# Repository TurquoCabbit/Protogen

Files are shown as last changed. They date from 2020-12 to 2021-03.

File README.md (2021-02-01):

# Protogen By Turquo Cabbit and Wolfgasm

* ## Environment setting guide at /firmware/00. environment_setting

* ## Run /firmware/Face2header/APP/New_Gens.exe to add new PROTOGEN or edit exist one
    * ### Enter {Protogen name}, color code, and REMOTE theme number
    * ### Enter face color for REMOTE : R, G, and B within 0 to 255
    * ### Enter REMOTE theme number, theme can be set at /firmware/image/color_theme, follow the folder arrange and naming rule of /00. cyber_neo

* ## Then Run /firmware/Face2header/APP/Face2header.exe to generate header files which content UUID for BLE and Face bitmap
    * ### Face was been set in /firmware/Face2header/Configure/{Protogen name}/LED Matrix.xlsx
    * ### Copy "empty" worksheet to the right of "empty" to add new face
    * ### Remember to fill in face name in the worksheet
    * ### The name of worksheets don't matter however the order of them will be the order of faces in REMOTE.
    * ### !!!DO NOT ADD OR REMOVE ANY WORKSHEET AT LEFT SIDE OF "empty" INCLUDE "empty" ITSELF!!!
    * ### Delete protogen use New_Gens.exe will delete its LED Matrix.xlsx as well, be careful

* ## Program /firmware/Protogen_matrixs/Protogen_matrixs.ino in to ESP32 at PROTOGEN_HEAD
    * ### Have to configur the app space as large as posibale in ESP32 (4MByte) first

* ## Program /firmware/ProtoGun/ProtoGun.ino in to TTGO T-Display in REMOTE
    * ### Have to configur the app space as large as posibale in ESP32 (4MByte) first

* ## TO DO
    * ### PROTOGEN_HEAD
        1. #### Update mainboard PCB made by Wolfgasm
        2. #### Faceture dittering
            * #### even during blinking
        3. #### Vocal sample with amp
            * #### use LM386 for mic amp and to speaker
            * #### ADC
        4. #### Optimize cpp code structure

    * ### REMOTE
        1. #### Translate REMOTE user guide
        2. #### Optimize cpp code structure

#####  Turquo   2021/02/01

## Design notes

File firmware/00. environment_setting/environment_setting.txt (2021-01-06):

00. Arduino Library
	Decompress libraries.zip to C:\Users\[your username]\Documents\Arduino\

01. ESP32_ram
	Copy "Mega_app.csv" to C:\Users\[your username]\AppData\Local\Arduino15\packages\esp32\hardware\esp32\1.0.4\tools\partitions
	Copy "boards.txt" to C:\Users\night\AppData\Local\Arduino15\packages\esp32\hardware\esp32\1.0.4

02. Vscode_ESP32_setting
	a. Install Arduino IDE
	b. Install Arduino plugin from Estensions in Vs code
	c. Fill in Arduino IDE installed path to "Arduino:path" in Vscode setting
	d. From "\02. Vscode_ESP32_setting\Protogen_matrixs" copy ".vscode" and "build_temp" to  "\firmware\Protogen_matrixs"
	e. From "\02. Vscode_ESP32_setting\ProtoGun" copy ".vscode" and "build_temp" to  "\firmware\ProtoGun"
	f. Com port number may be deferent modify it yourself while programing chip

Turquo	2021.01.06

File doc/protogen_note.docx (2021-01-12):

1. I2C Address of LED matrix
  1.1. 000 左邊鼻子 NOSE_L
  1.2. 001 右邊鼻子 NOSE_R
  1.3. 010 左邊眼睛 EYE_L
  1.4. 011 右邊眼睛 EYE_R
  1.5. 100 嘴巴左前 MOUTH_F_L
  1.6. 101 嘴巴右前 MOUTH_F_R
  1.7. 110 嘴巴左後 MOUTH_B_L
  1.8. 111 嘴巴右後 MOUTH_B_R
2. 線色
  2.1. Neopixel
    2.1.1. Vcc => Red
    2.1.2. Din => Blue
    2.1.3. GND => Black
    2.1.4. Dout => White
  2.2. LED Matrix
    2.2.1. Vcc => Red
    2.2.2. GND => Black
    2.2.3. SDA => Blue
    2.2.4. SCL => White
  2.3. PCB 8pin molex
    2.3.1. neopixel => Gray
    2.3.2. fan => Gray
    2.3.3. BZ => Gray
    2.3.4. 3V3 => Red
    2.3.5. SCL => White
    2.3.6. SDA => Blue
    2.3.7. GND => Black
    2.3.8. Vcc => Red
3. https://github.com/2dom/PxMatrix library for RGB matrix
4. E_can
  4.1. ~~風扇至於槍管中段，槍管前段放所有電路，握柄放電池~~
  4.2. 功能
    4.2.1. 螢幕
    4.2.2. 鋰電池電壓偵測/警告 (電壓偏低 風扇停轉，電壓過低關機)
    4.2.3. ~~紅外線搖控(發射/接收)~~
    4.2.4. BLE
    4.2.5. 風扇
      4.2.5.1. https://goods.ruten.com.tw/item/show?21733934233853
      4.2.5.2. BEC電調
    4.2.6. ~~繼電器開關(風扇+總開關)~~
    4.2.7. 按鈕 * 5
    4.2.8. 編碼器 * 1
    4.2.9. ~~DC-DC降壓至5V(LDO add??)~~
    4.2.10. 振動馬達 https://www.sparkfun.com/datasheets/Robotics/310-101_datasheet.pdf
  4.3. 開關機方案
    4.3.1. ~~單鍵開機，常按/選單關機(繼電器自保磁)~~
    4.3.2. ~~https://www.mouser.tw/datasheet/2/378/835-1146852.pdf~~
    4.3.3. 上電開機，偵測電池電壓足夠即開機，六秒後才可控風扇
    4.3.4. ~~長按Return 2秒關機~~
  4.4. 按鈕配置
    4.4.1. enter
    4.4.2. return
    4.4.3. FAN trigger
    4.4.4. X
    4.4.5. Y
    4.4.6. 編碼器 https://tech.alpsalpine.com/prod/c/pdf/encoder/incremental/ec10e/ec10e.pdf
  4.5. TTGO T-display (https://github.com/Xinyuan-LilyGO/TTGO-T-Display)
5. To Do
  5.1. faceture dittering fuction
    5.1.1. even when blinking
  5.2. Bz music
    5.2.1. Driver
    5.2.2. makefile
      5.2.2.1. 簡譜填寫
      5.2.2.2. 轉成陣列
  5.3. Vocal sencing
    5.3.1. LM386
    5.3.2. speaker
  5.4. offline operation
    5.4.1. offline saving
      5.4.1.1. only save remote/gun relate setting
    5.4.2. offline reset
      5.4.2.1. only reset remote/gun relate setting

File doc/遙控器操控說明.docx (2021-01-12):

# 遙控器操控說明

# 1. 主畫面

## 1.1. 顯示

    1.1.1. 頂端顯示電量
    1.1.2. 左下角顯示是否連接上Protogen
    1.1.3. 右下角顯示是否全開亮度
    1.1.4. 中間為當前的表情

## 1.2. 動作

    1.2.1. 滾輪切換表情
    1.2.2. 按一下 ”Enter” 鍵， 發送表情給Protogen
      1.2.2.1. 10 秒未按下Enter發送表情，螢幕將切回顯示當前表情
    1.2.3. 按一下 "X” 鍵，將在當前表情與常用表情間切換
      1.2.3.1. 常用表情設定見 2.3
    1.2.4. 按一下 "Y” 鍵，Beep
      1.2.4.1. Beep模式設定見 2.6.1
    1.2.5. 按一下 "Return" 鍵，LED陣列亮度將在當前亮度與最大亮度間切換
      1.2.5.1. LED陣列亮度設定見 2.4
    1.2.6. 按住"X" 鍵一秒，重新播放或停止動畫
    1.2.7. 按住"Y" 鍵一秒，進入名片頁面
      1.2.7.1. 滾輪翻頁
      1.2.7.2. 按一下任意鍵退出
    1.2.8. 按住 "Return" 鍵一秒進入設定模式

# 2. 設定模式

## 2.1. 按住 "Return" 鍵一秒返回主畫面(無儲存)

## 2.2. Start UP 開機表情

    2.2.1. 滾輪切換表情

## 2.3. Toggle 常用表情

    2.3.1. 滾輪切換表情

## 2.4. Matrix_Bright LED陣列亮度

    2.4.1. 滾輪調整亮度 (0 ~ 15)

## 2.5. Blink 眨眼週期

    2.5.1. 滾輪選擇週期 (2秒 ~ 30秒) 或關閉

## 2.6. BEEP Beep

    2.6.1. MODE 模式
      2.6.1.1. Single 單響
      2.6.1.2. Double 雙響
      2.6.1.3. Rand one 隨機音高單響
      2.6.1.4. Rand two 隨機音高雙響
      2.6.1.5. Rand three 隨機音高三響
      2.6.1.6. 滾輪選擇模式
    2.6.2. PERIOD 週期
      2.6.2.1. 滾輪選擇週期(1 ~ 15 次眨眼) 或關閉
    2.6.3. PITCH 音高
      2.6.3.1. 滾輪往上調高
      2.6.3.2. 滾輪往下調低

## 2.7. BOOP Protosence

    2.7.1. 目前僅有Boop功能
    2.7.2. 滾輪調整開啟或關閉

## 2.8. Neo_Bright Neopixel亮度

    2.8.1. 滾輪調整亮度 (0 ~ 255)

## 2.9. Fan Duty 風量

    2.9.1. 滾輪調整duty cycle (50% ~ 100%)

## 2.10. ADC Cal 電池電壓校準

    2.10.1. 滾輪調整ADC增益
    2.10.2. 將顯示的電池電壓調整至與測量結果相同

## 2.11. Leave 退出

    2.11.1. Don't Save
      2.11.1.1. 不儲存並回到主選單
    2.11.2. Save
      2.11.2.1. 將所有設定發送至Protogen並儲存後回到主選單

## 2.12. Reset 重置

    2.12.1. 按住 "Y" 鍵三秒重置
    2.12.2. 將同時重置連線的Protogen

# 3. 省電

  3.1. 一分鐘未操作UI，關閉LCD背光
  3.2. 按任意鍵(風扇板機除外)或滾動滾輪恢復

# 4. TODO

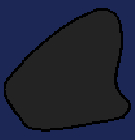
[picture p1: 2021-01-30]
firmware/image/color_theme/00. cyber_neo/Face/Face_empty.jpg

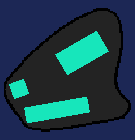
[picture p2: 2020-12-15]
firmware/image/Jpg/00. Spoon/03_Full.png

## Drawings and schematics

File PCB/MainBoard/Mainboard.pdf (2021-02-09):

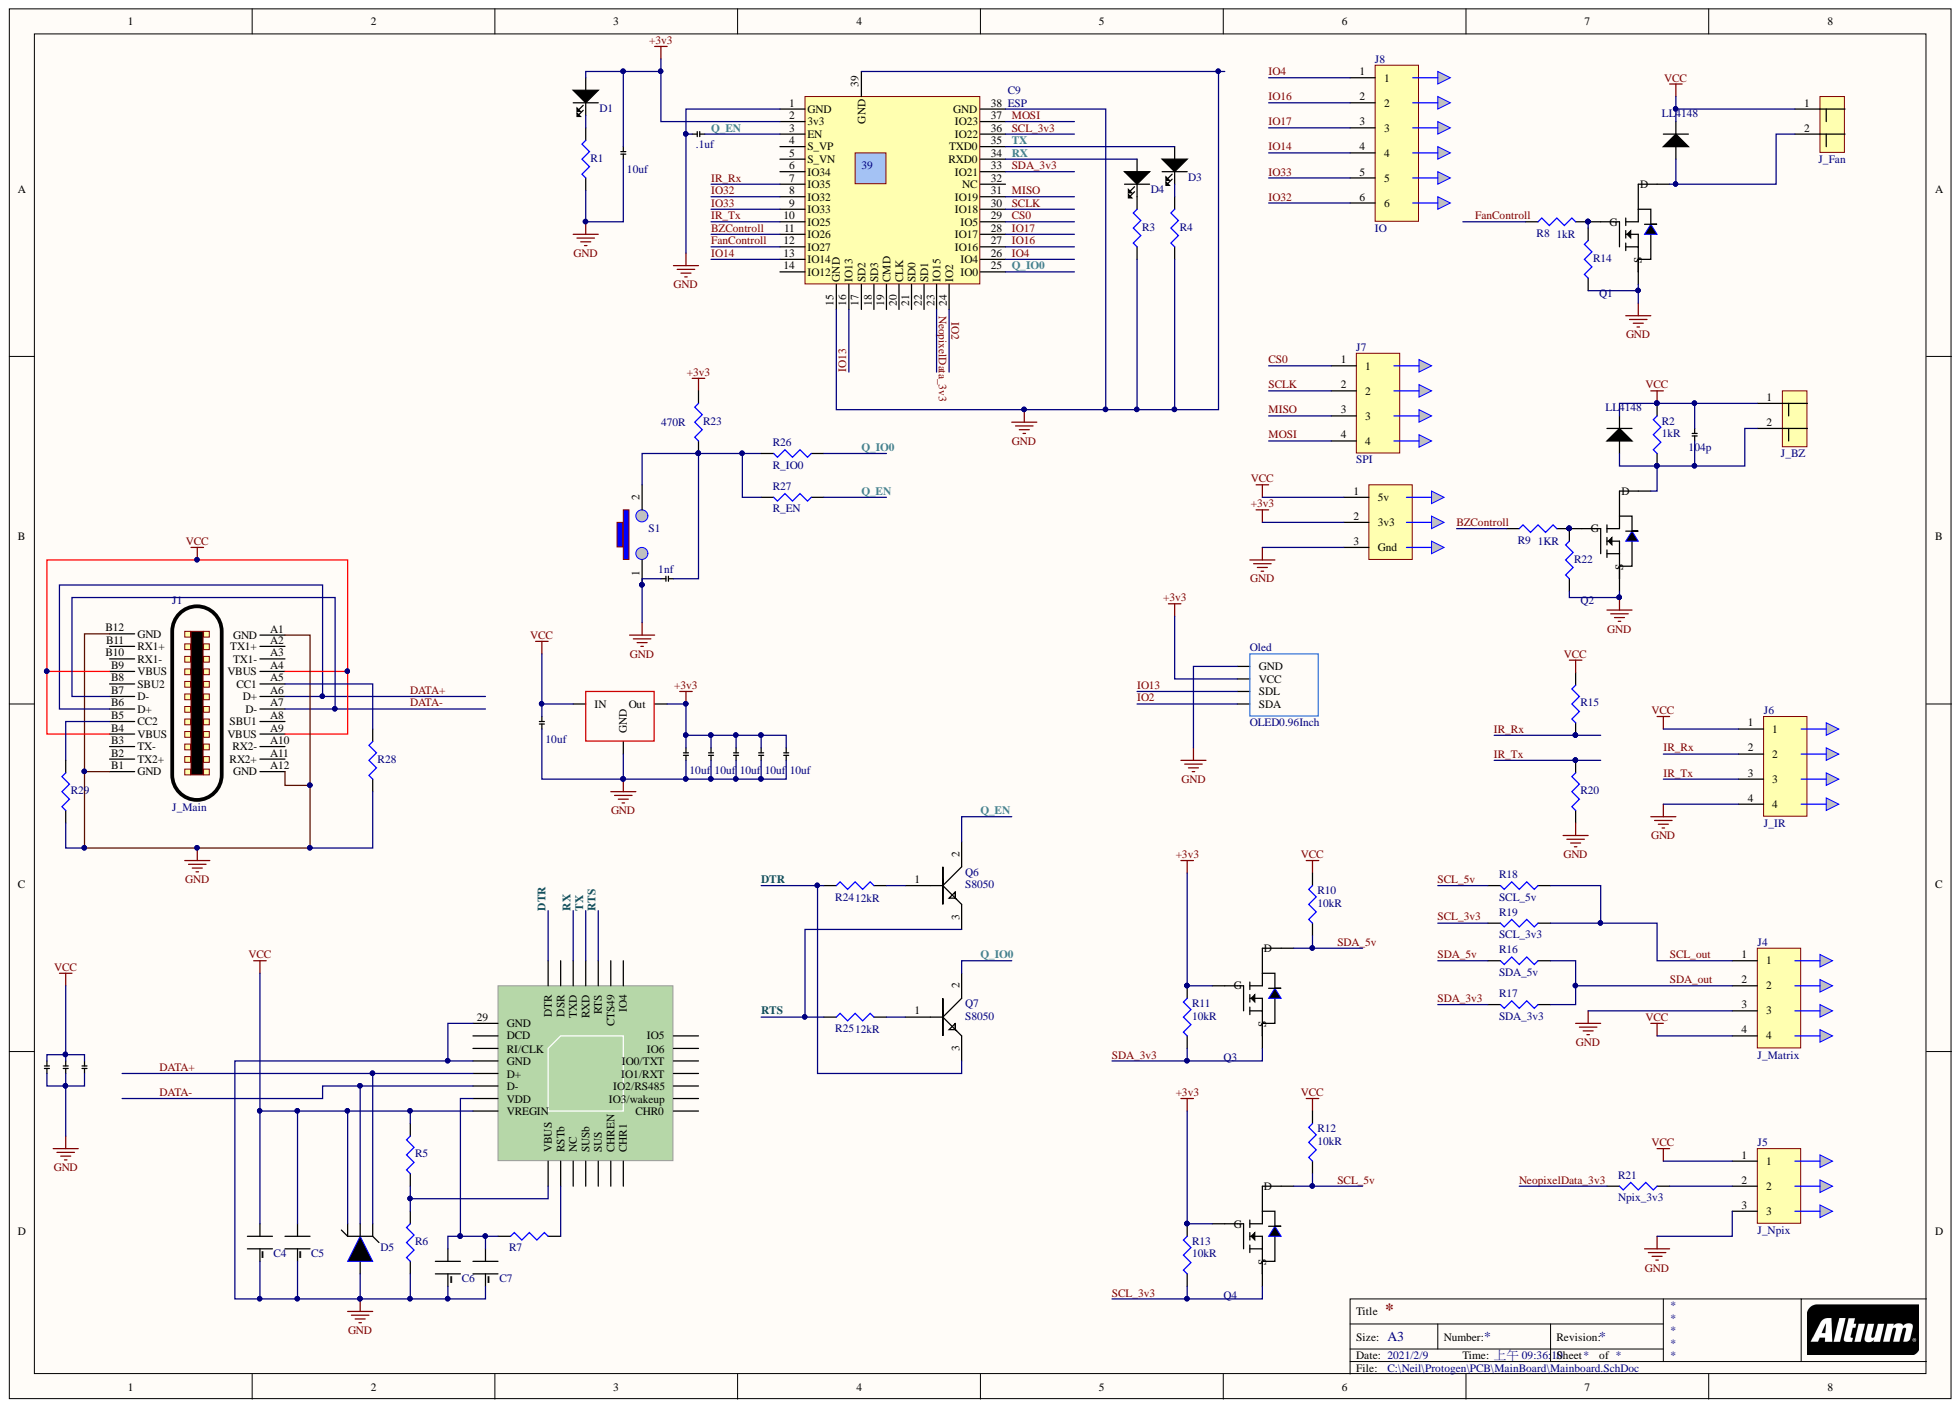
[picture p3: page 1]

SCL_3v3 | Q4

* Title | * * * * *

Size: A3 | Number: * | Revision: *
Date: 2021/2/9 Time: 上午 09:36:10 | | Sheet * of *

C:\Neil\Protogen\PCB\MainBoard\Mainboard.SchDoc

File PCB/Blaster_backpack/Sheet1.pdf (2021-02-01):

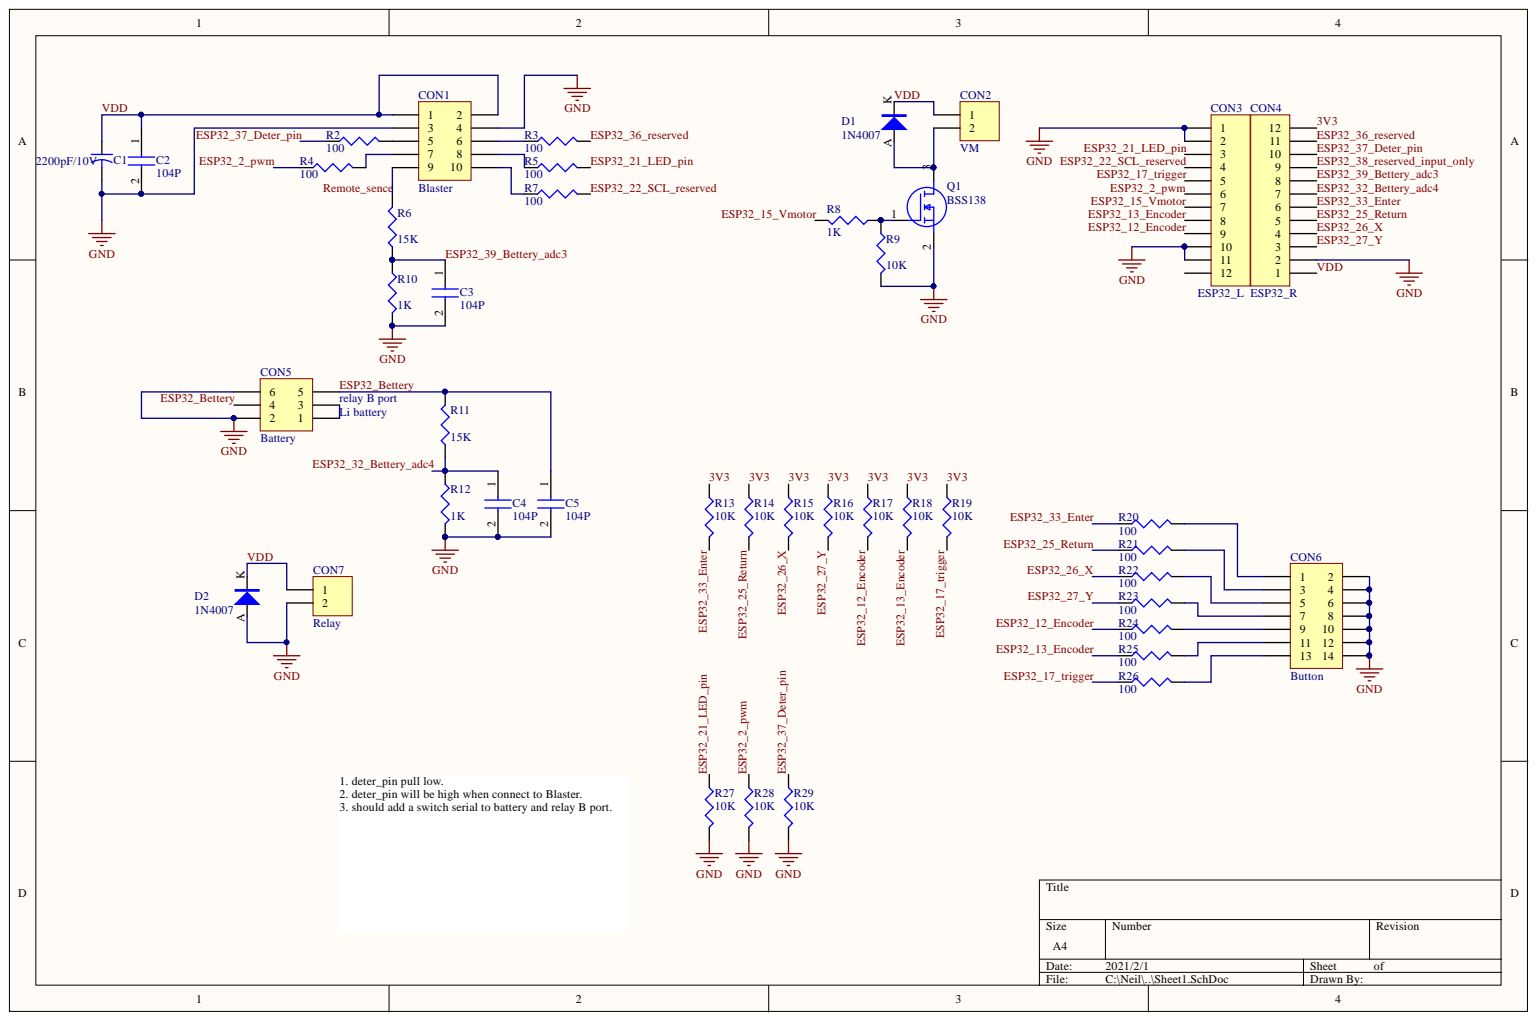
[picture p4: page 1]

1. deter_pin pull low.
2. deter_pin will be high when connect to Blaster.
3. should add a switch serial to battery and relay B port.

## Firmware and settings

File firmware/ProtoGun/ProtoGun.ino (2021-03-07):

#include <esp_task_wdt.h>
#include <driver/adc.h>
#include <TFT_eSPI.h>
#include <BLEDevice.h>
#include <BLEUtils.h>
#include <BLEServer.h>
#include <BLE2902.h>
#include <EEPROM.h>

#include "./Header Files/option.h"
#include "./Header Files/image.h"
#include "./Header Files/GPIO.h"
#include "./Header Files/parameter.h"
#include "./Header Files/LCD.h"
#include "./Header Files/ADC.h"
#include "./Header Files/BLE.h"


void setup()
{
	Serial.begin(115200);
	serial_log(0, "start up");
	gpio_init();

	parameter_init();
	
	queue_init();

	EEPROM.begin(EEPROM_SIZE);

	/*
	core_0	Fan, ADC, Ctrl, BLE, VM
	Core_1	GUI
	*/

	xTaskCreatePinnedToCore(
		GUI_task, /* Function to implement the task */
		"GUI_task", /* Name of the task */
		GUI_task_stack,  /* Stack size in words */
		NULL,  /* Task input parameter */
		GUI_task_priority,  /* Priority of the task */
		&GUI_task_handle,  /* Task handle. */
		core_1);

	xTaskCreatePinnedToCore(
		Fan_task, /* Function to implement the task */
		"Fan_task", /* Name of the task */
		Fan_task_stack,  /* Stack size in words */
		NULL,  /* Task input parameter */
		Fan_task_priority,  /* Priority of the task */
		&Fan_task_handle,  /* Task handle. */
		core_0);

	xTaskCreatePinnedToCore(
		ADC_task, /* Function to implement the task */
		"ADC_task", /* Name of the task */
		ADC_task_stack,  /* Stack size in words */
		NULL,  /* Task input parameter */
		ADC_task_priority,  /* Priority of the task */
		&ADC_task_handle,  /* Task handle. */
		core_0);

	xTaskCreatePinnedToCore(
		Ctrl_task, /* Function to implement the task */
		"Ctrl_task", /* Name of the task */
		Ctrl_task_stack,  /* Stack size in words */
		NULL,  /* Task input parameter */
		Ctrl_task_priority,  /* Priority of the task */
		&Ctrl_task_handle,  /* Task handle. */
		core_0);

	xTaskCreatePinnedToCore(
		BLE_task, /* Function to implement the task */
		"BLE_task", /* Name of the task */
		BLE_task_stack,  /* Stack size in words */
		NULL,  /* Task input parameter */
		BLE_task_priority,  /* Priority of the task */
		&BLE_task_handle,  /* Task handle. */
		core_0);

	xTaskCreatePinnedToCore(
		VM_task, /* Function to implement the task */
		"VM_task", /* Name of the task */
		VM_task_stack,  /* Stack size in words */
		NULL,  /* Task input parameter */
		VM_task_priority,  /* Priority of the task */
		&VM_task_handle,  /* Task handle. */
		core_0);

	serial_log(0, "create task done");

	if (EEPROM.read(EEPROM_Addr_Saved) == EEPROM_saved)
	{
		EEPROM_Load();
		serial_log(0, "Load EEPROM done");
	}

	ADC_mode(ADC_mode_pre_boost);
}

void loop()
{
	//core 1
	vTaskDelete(NULL); //Kill Loop()
}

void Fan_task(void * parameter)
{
	uint8_t mode = 0xFF;
	bool Fan_status = 0;
	uint32_t Fan_on_cnt = 0;
	for (;;)
	{
		if (xQueueReceive(queue_Fan, &mode, portMAX_DELAY) == pdTRUE)
		{
			switch (mode)
			{
			case Fan_mode_boost:
				Set_pwm(50, Fan_channel);
				vTaskDelay(6000 / portTICK_PERIOD_MS);
				Fan_mode(Fan_mode_general);
				break;
			case Fan_mode_off:
				Set_pwm(0, Fan_channel);
				vTaskDelete(NULL);
				break;
			case Fan_mode_general:
				if (Blaster.Fan_ready && Fan_on_cnt < Fan_on_Max_time)
				{
					if (Get_But_press(&But_Trigger) && !Fan_status)
					{
						if (Blaster.Fan_duty > 100)
						{
							Blaster.Fan_duty = 100;
						}
						else if (Blaster.Fan_duty < 50)
						{
							Blaster.Fan_duty = 50;
						}
						serial_log(0, "Fan on");
						Fan_status = 1;
						Set_pwm(Blaster.Fan_duty, Fan_channel);
					}
					else if(!Get_But_press(&But_Trigger) && Fan_status)
					{
						serial_log(0, "Fan off");
						Fan_status = 0;
						Set_pwm(50, Fan_channel);
					}
					if(Fan_status)
					{
						Fan_on_cnt += Fan_scan_cycle_time;
					}
					vTaskDelay(Fan_scan_cycle_time / portTICK_PERIOD_MS);
					Fan_mode(Fan_mode_general);
				}
				else
				{
					if (Fan_status)
					{
						Fan_status = 0;
						Set_pwm(50, Fan_channel);
					}
					if(Fan_on_cnt)
					{
						Fan_on_cnt = 0;
					}
				}
				break;
			}
		}
	}
}

void ADC_task(void * parameter)
{
	uint8_t mode = 0xFF;
	bool Deter_pin_temp = 0;
	bool ADC_initiated = 0;
	uint32_t ADC_average_cnt = 0;
	uint64_t ADC_average = 0;
	for (;;)
	{
		if (xQueueReceive(queue_ADC, &mode, portMAX_DELAY) == pdTRUE)
		{
			switch (mode)
			{
			case ADC_mode_pre_boost:
				ADC_average_cnt = 0;
				ADC_average = 0;
				vTaskDelay(50 / portTICK_PERIOD_MS);
				Blaster.remote = Get_Deter_pin(Deter_PIN);
				if (Blaster.remote)		//Blaster Deter_PIN low
				{
					Blaster.Fan_ready = 0;
					serial_log(0, "remote");
				}
				else					//Remote Deter_PIN high
				{
					Blaster.Fan_ready = 1;
					serial_log(0, "BLASTER");
				}
				if(!ADC_initiated)
				{
					ADC_init();
					ADC_initiated = 1;
				}
				Battery_level_init();
				Deter_pin_temp = Get_Deter_pin(Deter_PIN);
				vTaskDelay(5 / portTICK_PERIOD_MS);

			case ADC_mode_boost:
				if(ADC_average_cnt < ADC_init_average_time)
				{
					if(Blaster.remote != Deter_pin_temp)
					{
						ADC_mode(ADC_mode_pre_boost);
					}
					else
					{
						ADC_average += ADC_convert(Blaster.remote);
						ADC_average_cnt += ADC_init_scan_intervial;
						Deter_pin_temp = Get_Deter_pin(Deter_PIN);
						vTaskDelay(ADC_init_scan_intervial / portTICK_PERIOD_MS);
					}
				}
				else
				{
					Blaster.ADC_value = ADC_average / (ADC_init_average_time / ADC_init_scan_intervial);
					ADC_average_cnt = 0;
					ADC_average = 0;
					if (Blaster.ADC_value > Battery_level.Break && ADC_initiated == 1)
					{
						serial_log("Vol", (float)(Blaster.ADC_value) / Blaster.ADC_gain);
						Ctrl_mode(Ctrl_mode_boost);
					}
					else
					{
						serial_log(0, "BATT BREAK");
						serial_log("Vol", (float)(Blaster.ADC_value) / Blaster.ADC_gain);
						serial_log("Break", (float)(Battery_level.Break) / Blaster.ADC_gain);
						ADC_mode(ADC_mode_terminate);
					}
					vTaskDelay(ADC_init_pause_time / portTICK_PERIOD_MS);
				}
				ADC_mode(ADC_mode_boost);
				break;

			case ADC_mode_general:
				if (ADC_average_cnt < ADC_average_time)
				{
					ADC_average += ADC_convert(Blaster.remote);
					ADC_average_cnt += ADC_scan_intervial;
					Deter_pin_temp = Get_Deter_pin(Deter_PIN);
					vTaskDelay(ADC_scan_intervial / portTICK_PERIOD_MS);
				}
				else
				{
					ADC_mode(ADC_mode_calculation);
				}
				ADC_mode(ADC_mode_general);
				break;

			case ADC_mode_calculation:			
				Blaster.ADC_value = ADC_average / (ADC_average_time / ADC_scan_intervial);
				ADC_average_cnt = 0;
				ADC_average = 0;
				serial_log("Vol", (float)(Blaster.ADC_value) / Blaster.ADC_gain);
				if (Blaster.ADC_value < Battery_level.Break && Blaster.Power_Low)
				{
					Blaster.Power_Low = 1;
					Blaster.Power_Break = 1;
					Blaster.Fan_ready = 0;
					serial_log(0, "BATT BREAK");
					serial_log("Vol", (float)(Blaster.ADC_value) / Blaster.ADC_gain);
					serial_log("Break", (float)(Battery_level.Break) / Blaster.ADC_gain);
					ESP.restart();
				}
				else if (Blaster.ADC_value < Battery_level.Low)
				{
					Blaster.Power_Low = 1;
					Blaster.Fan_ready = 0;
				}
				else
				{
					Blaster.Power_Low = 0;
					Blaster.Power_Break = 0;
				}
				Blaster.Battery = (Blaster.ADC_value - Battery_level.Break) * 5 / (Battery_level.Full - Battery_level.Break);
				serial_log("Bat_L", Blaster.Battery);
				LCD_refresh_cnt.ADC = 1;
				vTaskDelay(ADC_pause_time / portTICK_PERIOD_MS);
				ADC_mode(ADC_mode_general);
				break;
				
			case ADC_mode_terminate:
				GUI_mode(GUI_mode_off);
				Fan_mode(Fan_mode_off);
				Ctrl_mode(Ctrl_mode_off);
				BLE_mode(BLE_mode_off);
				VM_mode(VM_mode_off);
				vTaskDelay(10 / portTICK_PERIOD_MS);
				esp_deep_sleep_start();

			case ADC_mode_off:
				vTaskDelete(NULL);
				break;
			}
		}
	}
}

void GUI_task(void * parameter)
{
	uint8_t mode = 0xFF;
	uint8_t sleep_mode;
	uint8_t Face_show_index, setting_list_index = 0, leave_index = 1, beep_index = 0;
	uint8_t Face_toggle_temp;
	uint32_t temp_32 = GUI_temp32_init;
	uint16_t temp_16 = GUI_temp16_init;
	bool Max_brightness = 0;
	bool BLE_connect_last = BLE_connected;
	bool show = 0;
	bool toggled = 0;
	char temp_str[20];
	bool LCD_initiated = 0;
	for (;;)
	{
		if (xQueueReceive(queue_GUI, &mode, portMAX_DELAY) == pdTRUE)
		{
			switch (mode)
			{
			case GUI_mode_boost:
				if(!LCD_initiated)
				{
					LCD_init();
					LCD_initiated = 1;
				}
				Face_show_index = Blaster.Face_index;
				clear_encoder_flag();
				GUI_mode(GUI_mode_main);
				LCD_refresh_cnt.Face_resume = Face_resume_time + 1;
				break;

			case GUI_mode_off:
				if(LCD_initiated)
				{
					tft.fillScreen(TFT_WHITE);  // clean screen
				}
				digitalWrite(TFT_BL, 0); //turn off backlight
				vTaskDelete(NULL);
				break;

			case GUI_mode_sleep:
				digitalWrite(TFT_BL, 0); //turn off backlight
				if (Get_But(&But_X) || Get_But(&But_Y) || Get_But(&But_Enter) || Get_But(&But_Return) || Encoder_down || Encoder_up) //wake up
				{
					digitalWrite(TFT_BL, 1); //turn on backlight
					LCD_sleep_cnt = 0;
					clear_encoder_flag();
					GUI_mode(sleep_mode);
				}
				else
				{
					vTaskDelay(50 / portTICK_PERIOD_MS);
					GUI_mode(GUI_mode_sleep);
				}
				break;

			case GUI_mode_main:
				sleep_mode = mode;
				// Battery status=====================================
				if (LCD_refresh_cnt.Batt == Batt_refresh_time || show)
				{
					LCD_refresh_cnt.Batt = 0;

					if (Blaster.Battery < 5)
					{
						LCD_show_Battery(Batt[Blaster.Battery]);
					}
					else
					{
						LCD_show_Battery(Batt[4]);
					}
				}

				// Info===============================================
				if (LCD_refresh_cnt.info == info_refresh_time || show)
				{
					LCD_refresh_cnt.info = 0;

					if (BLE_connect_last)
					{
						LCD_show_BLE(Connected);
					}
					else
					{
						LCD_show_BLE(Unconnected);
					}

					if (Max_brightness)
					{
						LCD_show_lit(Max_lit);
					}
					else
					{
						LCD_show_lit(general_lit);
					}
				}

				// Main===============================================
				if (LCD_refresh_cnt.main == main_refresh_time || show)
				{
					show = 0;
					LCD_refresh_cnt.main = 0;
					LCD_show_main(Face[Face_show_index]);
				}

				//BLE connect status refresh
				if (BLE_connect_last != BLE_connected)
				{
					LCD_refresh_cnt.info = 1;
					BLE_connect_last = BLE_connected;
				}
				
				//Select face			Roll
				if (Encoder_down)
				{
					Encoder_down = 0;
					if (Face_show_index < Face_index_top)
					{
						Face_show_index++;
						LCD_refresh_cnt.main = 1;
					}
					LCD_refresh_cnt.Face_resume = 0;
				}
				else if (Encoder_up)
				{
					Encoder_up = 0;
					if (Face_show_index > 0)
					{
						Face_show_index--;
						LCD_refresh_cnt.main = 1;
					}
					LCD_refresh_cnt.Face_resume = 0;
				}
				
				//resume face after 10s
				if (LCD_refresh_cnt.Face_resume == Face_resume_time && Face_show_index != Blaster.Face_index)
				{
					serial_log(0, "resume face");
					VM_mode(VM_mode_on_long);
					LCD_refresh_cnt.Face_resume = Face_resume_time + 1;
					Face_show_index = Blaster.Face_index;
					LCD_refresh_cnt.main = 1;
				}

				//Set face				Enter
				if (Get_But(&But_Enter))
				{
					VM_mode(VM_mode_on_long);
					if(ProtoGun_setCMD(Face_cmd[Face_show_index]))
					{
						serial_log(0, "Set face");
						Blaster.Face_index = Face_show_index;
						if (toggled)
						{
							toggled = 0;
						}
						
						LCD_refresh_cnt.Face_resume = Face_resume_time + 1;
						BLE_mode(BLE_mode_notify);
					}
				}

				//Fast toggle face		X
				if (Get_But(&But_X))
				{
					VM_mode(VM_mode_on_long);
					if(!toggled ? ProtoGun_setCMD(Face_cmd[Blaster.Face_toggle_index]) : ProtoGun_setCMD(Face_cmd[Face_toggle_temp]))
					{
						serial_log(0, "Toggle face");
						if (!toggled)
						{
							Face_toggle_temp = Blaster.Face_index;
							Blaster.Face_index = Blaster.Face_toggle_index;
							Face_show_index = Blaster.Face_toggle_index;
							toggled = 1;
						}
						else
						{
							Face_show_index = Face_toggle_temp;
							Blaster.Face_index = Face_toggle_temp;
							toggled = 0;
						}					
						LCD_refresh_cnt.main = 1;
						BLE_mode(BLE_mode_notify);
					}
				}

				//Fast animate		Hold X 1sec
				if (Get_But(&But_X, 1000))
				{
					VM_mode(VM_mode_on_long);
					if(ProtoGun_setCMD(0x1A0))    //Fast animate
					{
						serial_log(0, "Replay animate");
						BLE_mode(BLE_mode_notify);
					}
				}

				//Fast Beep		Y
				if (Get_But(&But_Y))
				{
					VM_mode(VM_mode_on_long);
					if(ProtoGun_setCMD(0x000))    //Beep
					{
						serial_log(0, "Beep");
						BLE_mode(BLE_mode_notify);
					}
				}

				//Fast brightness		Return
				if (Get_But(&But_Return))
				{
					serial_log(0, "Brightness");
					VM_mode(VM_mode_on_long);
					if (!Max_brightness)
					{
						if(ProtoGun_setCMD(0x10F))    //Matrix Brightness_15
						{
							Max_brightness = 1;							
							BLE_mode(BLE_mode_notify);
							LCD_refresh_cnt.info = 1;
						}
					}
					else
					{
						if(ProtoGun_setCMD(0x100 + Blaster.Matrix_Brightness))
						{
							Max_brightness = 0;
							BLE_mode(BLE_mode_notify);
							LCD_refresh_cnt.info = 1;
						}
					}
				}

				//Setting				Hold return 1sec
				if (Get_But(&But_Return, 1000))
				{
					serial_log(0, "Setting");
					VM_mode(VM_mode_on_long);
					show = 1;
					setting_list_index = 0;
					GUI_mode(GUI_mode_setting);
				}

				//Signature				Hold Y 1sec
				else if (Get_But(&But_Y, 1000))
				{
					serial_log(0, "Signature");
					VM_mode(VM_mode_on_long);
					temp_16 = GUI_temp16_init;
					temp_32 = GUI_temp32_init;
					show = 1;
					GUI_mode(GUI_mode_signature);
				}
				else
				{
					GUI_mode(GUI_mode_main);
				}
				break;

			case GUI_mode_setting:
				sleep_mode = mode;
				if (show)
				{
					show = 0;
					LCD_show_list(Setting_list, setting_list_index, setting_list_top);
				}

				if (Encoder_down)
				{
					Encoder_down = 0;
					if (setting_list_index)
					{
						setting_list_index--;
						show = 1;
					}
				}
				else if (Encoder_up)
				{
					Encoder_up = 0;
					if (setting_list_index < setting_list_top)
					{
						setting_list_index++;
						show = 1;
					}
				}

				if (Get_But(&But_Enter))
				{
					VM_mode(VM_mode_on_long);
					show = 1;
					temp_32 = GUI_temp32_init;
					temp_16 = GUI_temp16_init;
					if(setting_list_index == (GUI_mode_ADC - GUI_mode_startface))
					{
						LCD_refresh_cnt.ADC = 1;
					}
					GUI_mode(GUI_mode_startface + setting_list_index);
				}
				else if (Get_But(&But_Return, 1000))
				{
					VM_mode(VM_mode_on_long);
					show = 1;
					temp_32 = GUI_temp32_init;
					temp_16 = GUI_temp16_init;
					GUI_mode(GUI_mode_main);
				}
				else
				{
					GUI_mode(GUI_mode_setting);
				}
				break;

			case GUI_mode_startface:
				sleep_mode = mode;
				if (temp_16 == GUI_temp16_init)
				{
					temp_16 = Blaster.Face_startup_index;
				}
				if (show)
				{
					show = 0;
					tft.fillScreen(TFT_BLACK);  // clean screen
					LCD_show_title(Setting_list, setting_list_index);
					LCD_show_main(Face[Blaster.Face_startup_index]);
				}

				if (Encoder_down)
				{
					Encoder_down = 0;
					if (Blaster.Face_startup_index > 0)
					{
						Blaster.Face_startup_index--;
						show = 1;
					}
				}
				else if (Encoder_up)
				{
					Encoder_up = 0;
					if (Blaster.Face_startup_index < Face_index_top)
					{
						Blaster.Face_startup_index++;
						show = 1;
					}
				}

				if (Get_But(&But_Enter))
				{
					VM_mode(VM_mode_on_long);
					show = 1;
					GUI_mode(GUI_mode_setting);
				}
				else if (Get_But(&But_Return))
				{
					VM_mode(VM_mode_on_long);
					show = 1;
					Blaster.Face_startup_index = temp_16;
					GUI_mode(GUI_mode_setting);
				}
				else
				{
					GUI_mode(GUI_mode_startface);
				}
				break;

			case GUI_mode_toggleface:
				sleep_mode = mode;
				if (temp_16 == GUI_temp16_init)
				{
					temp_16 = Blaster.Face_toggle_index;
				}
				if (show)
				{
					show = 0;
					tft.fillScreen(TFT_BLACK);  // clean screen
					LCD_show_title(Setting_list, setting_list_index);
					LCD_show_main(Face[Blaster.Face_toggle_index]);
				}

				if (Encoder_down)
				{
					Encoder_down = 0;
					if (Blaster.Face_toggle_index > 0)
					{
						Blaster.Face_toggle_index--;
						show = 1;
					}
				}
				else if (Encoder_up)
				{
					Encoder_up = 0;
					if (Blaster.Face_toggle_index < Face_index_top)
					{
						Blaster.Face_toggle_index++;
						show = 1;
					}
				}

				if (Get_But(&But_Enter))
				{
					VM_mode(VM_mode_on_long);
					show = 1;
					GUI_mode(GUI_mode_setting);
				}
				else if (Get_But(&But_Return))
				{
					VM_mode(VM_mode_on_long);
					show = 1;
					Blaster.Face_toggle_index = temp_16;
					GUI_mode(GUI_mode_setting);
				}
				else
				{
					GUI_mode(GUI_mode_toggleface);
				}
				break;

			case GUI_mode_Matrix_brightness:
				sleep_mode = mode;
				if (temp_16 == GUI_temp16_init)
				{
					temp_16 = Blaster.Matrix_Brightness;
				}
				if (show)
				{
					show = 0;
					tft.fillScreen(TFT_BLACK);  // clean screen
					LCD_show_title(Setting_list, setting_list_index);

					Font_set_min();
					tft.setCursor(0, 120);
					tft.setTextColor(TFT_WHITE);
					tft.setTextSize(1);
					sprintf(temp_str, "   %02d", Blaster.Matrix_Brightness);
					tft.printf(temp_str);
				}

				if (Encoder_down)
				{
					Encoder_down = 0;
					if (Blaster.Matrix_Brightness > 0)
					{
						Blaster.Matrix_Brightness--;
						if(ProtoGun_setCMD(0x100 + Blaster.Matrix_Brightness))    //Matrix Brightness
						{
							BLE_mode(BLE_mode_notify);
							show = 1;
						}
						else
						{
							Blaster.Matrix_Brightness++;
						}
					}
				}
				else if (Encoder_up)
				{
					Encoder_up = 0;
					if (Blaster.Matrix_Brightness < 15)
					{
						Blaster.Matrix_Brightness++;
						if(ProtoGun_setCMD(0x100 + Blaster.Matrix_Brightness))    //Matrix Brightness
						{
							BLE_mode(BLE_mode_notify);
							show = 1;
						}
						else
						{
							Blaster.Matrix_Brightness--;
						}
					}
				}

				if (Get_But(&But_Enter))
				{
					VM_mode(VM_mode_on_long);
					show = 1;
					GUI_mode(GUI_mode_setting);
				}
				else if (Get_But(&But_Return))
				{
					VM_mode(VM_mode_on_long);
					show = 1;
					Blaster.Matrix_Brightness = temp_16;
					if(ProtoGun_setCMD(0x100 + Blaster.Matrix_Brightness))    //Matrix Brightness
					{
						BLE_mode(BLE_mode_notify);
					}
					GUI_mode(GUI_mode_setting);
				}
				else
				{
					GUI_mode(GUI_mode_Matrix_brightness);
				}
				break;

			case GUI_mode_blink:
				sleep_mode = mode;
				if (temp_16 == GUI_temp16_init)
				{
					temp_16 = Blaster.Blink_period;
				}
				if (show)
				{
					show = 0;
					tft.fillScreen(TFT_BLACK);  // clean screen
					LCD_show_title(Setting_list, setting_list_index);

					Font_set_min();
					tft.setCursor(0, 100);
					tft.setTextColor(TFT_WHITE);
					tft.setTextSize(1);
					if (Blaster.Blink_period)
					{
						sprintf(temp_str, "   %02d s", Blaster.Blink_period * 2);
					}
					else
					{
						sprintf(temp_str, "   OFF");
					}
					tft.printf(temp_str);
				}

				if (Encoder_down)
				{
					Encoder_down = 0;
					if (Blaster.Blink_period > 0)
					{
						Blaster.Blink_period--;
						show = 1;
					}
				}
				else if (Encoder_up)
				{
					Encoder_up = 0;
					if (Blaster.Blink_period < 15)
					{
						Blaster.Blink_period++;
						show = 1;
					}
				}

				if (Get_But(&But_Enter))
				{
					VM_mode(VM_mode_on_long);
					show = 1;
					GUI_mode(GUI_mode_setting);
				}
				else if (Get_But(&But_Return))
				{
					VM_mode(VM_mode_on_long);
					show = 1;
					Blaster.Blink_period = temp_16;
					GUI_mode(GUI_mode_setting);
				}
				else
				{
					GUI_mode(GUI_mode_blink);
				}
				break;

			case GUI_mode_beep:
				sleep_mode = mode;
				if (show)
				{
					show = 0;
					tft.fillScreen(TFT_BLACK);  // clean screen
					LCD_show_title(Setting_list, setting_list_index);
					LCD_show_list(Beep_list, beep_index, beep_list_top);
				}

				if (Encoder_down)
				{
					Encoder_down = 0;
					if (beep_index)
					{
						beep_index--;
						show = 1;
					}
				}
				else if (Encoder_up)
				{
					Encoder_up = 0;
					if (beep_index < beep_list_top)
					{
						beep_index++;
						show = 1;
					}
				}

				if (Get_But(&But_Enter))
				{
					VM_mode(VM_mode_on_long);
					show = 1;
					temp_16 = GUI_temp16_init;
					GUI_mode(GUI_mode_beep_mode + beep_index);
				}
				else if (Get_But(&But_Return))
				{
					VM_mode(VM_mode_on_long);
					show = 1;
					beep_index = 0;
					GUI_mode(GUI_mode_setting);
				}
				else
				{
					GUI_mode(GUI_mode_beep);
				}
				break;

			case GUI_mode_beep_mode:
				sleep_mode = mode;
				if (temp_16 == GUI_temp16_init)
				{
					temp_16 = Blaster.Beep_mode;
				}
				if (show)
				{
					show = 0;
					tft.fillScreen(TFT_BLACK);  // clean screen
					LCD_show_title(Beep_list, beep_index);
					LCD_show_list(Beep_mode_list, Blaster.Beep_mode, beep_mode_list_top);
				}

				if (Encoder_down)
				{
					Encoder_down = 0;
					if (Blaster.Beep_mode)
					{
						Blaster.Beep_mode--;
						show = 1;
					}
				}
				else if (Encoder_up)
				{
					Encoder_up = 0;
					if (Blaster.Beep_mode < beep_mode_list_top)
					{
						Blaster.Beep_mode++;
						show = 1;
					}
				}

				if (Get_But(&But_Enter))
				{
					VM_mode(VM_mode_on_long);
					show = 1;
					GUI_mode(GUI_mode_beep);
				}
				else if (Get_But(&But_Return))
				{
					VM_mode(VM_mode_on_long);
					show = 1;
					Blaster.Beep_mode = temp_16;
					GUI_mode(GUI_mode_beep);
				}
				else
				{
					GUI_mode(GUI_mode_beep_mode);
				}
				break;

			case GUI_mode_beep_period:
				sleep_mode = mode;
				if (temp_16 == GUI_temp16_init)
				{
					temp_16 = Blaster.Beep_period;
				}
				if (show)
				{
					show = 0;
					tft.fillScreen(TFT_BLACK);  // clean screen
					LCD_show_title(Beep_list, beep_index);
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

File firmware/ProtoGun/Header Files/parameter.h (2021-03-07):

#define core_0 0
#define core_1 1

//task_priority 0 to (configMAX_PRIORITIES - 1)
#define Fan_task_priority				5
#define ADC_task_priority				5
#define Ctrl_task_priority				6
#define BLE_task_priority				5
#define VM_task_priority				5
#define GUI_task_priority				6

//stack size in word
#define Fan_task_stack					1024
#define ADC_task_stack					2048
#define Ctrl_task_stack					1024
#define BLE_task_stack					4096
#define VM_task_stack					1024
#define GUI_task_stack					4096

//Task Handle
TaskHandle_t Fan_task_handle;
TaskHandle_t ADC_task_handle;
TaskHandle_t Ctrl_task_handle;
TaskHandle_t BLE_task_handle;
TaskHandle_t VM_task_handle;
TaskHandle_t GUI_task_handle;

#define queue_mode_num 256
uint8_t queue_mode[queue_mode_num];  //mode 0 to 255

//Queue Handle
QueueHandle_t queue_Fan;
QueueHandle_t queue_ADC;
QueueHandle_t queue_Ctrl;
QueueHandle_t queue_BLE;
QueueHandle_t queue_VM;
QueueHandle_t queue_GUI;

inline void queue_init(void)
{
	queue_Fan = xQueueCreate(1, 1);       //1 items, 1 byte each
	queue_ADC = xQueueCreate(1, 1);       //1 items, 1 byte each
	queue_Ctrl = xQueueCreate(1, 1);      //1 items, 1 byte each
	queue_BLE = xQueueCreate(1, 1);       //1 items, 1 byte each
	queue_VM = xQueueCreate(1, 1);       //1 items, 1 byte each
	queue_GUI = xQueueCreate(1, 1);       //1 items, 1 byte each

	for (uint16_t i = 0; i < queue_mode_num; i++)
	{
		queue_mode[i] = i;
	}
}

#if Fan_fsm_log
	#define Fan_mode(mode)	{xQueueSend(queue_Fan, queue_mode + mode, 0); serial_log("Fan_fsm", mode);}
#else
	#define Fan_mode(mode)	xQueueSend(queue_Fan, queue_mode + mode, 0)
#endif
#if ADC_fsm_log
	#define ADC_mode(mode)	{xQueueSend(queue_ADC, queue_mode + mode, 0); serial_log("ADC_fsm", mode);}
#else
	#define ADC_mode(mode)	xQueueSend(queue_ADC, queue_mode + mode, 0)
#endif
#if Ctrl_fsm_log
	#define Ctrl_mode(mode)	{xQueueSend(queue_Ctrl, queue_mode + mode, 0); serial_log("Ctrl_fsm", mode);}
#else
	#define Ctrl_mode(mode)	xQueueSend(queue_Ctrl, queue_mode + mode, 0)
#endif
#if BLE_fsm_log
	#define BLE_mode(mode)	{xQueueSend(queue_BLE, queue_mode + mode, 0); serial_log("BLE_fsm", mode);}
#else
	#define BLE_mode(mode)	xQueueSend(queue_BLE, queue_mode + mode, 0)
#endif
#if VM_fsm_log
	#define VM_mode(mode)	{xQueueSend(queue_VM, queue_mode + mode, 0); serial_log("VM_fsm", mode);}
#else
	#define VM_mode(mode)	xQueueSend(queue_VM, queue_mode + mode, 0)
#endif
#if GUI_fsm_log
	#define GUI_mode(mode)	{xQueueSend(queue_GUI, queue_mode + mode, 0); serial_log("GUI_fsm", mode);}
#else
	#define GUI_mode(mode)	xQueueSend(queue_GUI, queue_mode + mode, 0)
#endif


enum _Fan_mode
{
	Fan_mode_boost		= 0xFF,
	Fan_mode_off		= 0xF0,
	Fan_mode_general	= 0x00,
};

enum _ADC_mode
{
	ADC_mode_pre_boost	= 0xFF,
	ADC_mode_boost		= 0xFE,
	ADC_mode_off		= 0xF0,
	ADC_mode_general	= 0x00,
	ADC_mode_calculation,
	ADC_mode_terminate,
};

enum _Ctrl_mode
{
	Ctrl_mode_boost		= 0xFF,
	Ctrl_mode_off		= 0xF0,
	Ctrl_mode_general	= 0x00,
};

enum _BLE_mode
{
	BLE_mode_boost		= 0xFF,
	BLE_mode_off		= 0xF0,
	BLE_mode_general	= 0x00,
	BLE_mode_notify,
};

enum _VM_mode
{
	VM_mode_boost			= 0xFF,
	VM_mode_off				= 0xF0,
	VM_mode_on_short		= 0x00,
	VM_mode_on_short_twice,
	VM_mode_on_short_thrice,
	VM_mode_on_long			= 0x10,
	VM_mode_on_long_twice,
	VM_mode_on_long_thrice,
	VM_mode_on_extra_long	= 0x20,
	VM_mode_on_extra_long_twice,
	VM_mode_on_extra_long_thrice,
};

enum _GUI_mode
{
	GUI_mode_boost				= 0xFF,
 	GUI_mode_save				= 0xFE,
 	GUI_mode_sleep				= 0xFD,
	GUI_mode_off				= 0xF0,
	GUI_mode_main				= 0x01,
	GUI_mode_setting,
	GUI_mode_startface			= 0x10,
	GUI_mode_toggleface,
	GUI_mode_Matrix_brightness,
	GUI_mode_blink,
 	GUI_mode_beep,
 	GUI_mode_boop,
 	GUI_mode_Neo_brightness,
 	GUI_mode_Fan,
 	GUI_mode_ADC,
 	GUI_mode_leave,
 	GUI_mode_reset,
 	GUI_mode_beep_mode			= 0x30,
 	GUI_mode_beep_period,
 	GUI_mode_beep_pitch,
 	GUI_mode_signature			= 0xA0,
};

#define GUI_temp32_init		0xFFFF0000
#define GUI_temp16_init		0xFF00

typedef struct _system_status
{
	bool Power_Low		:1;
	bool Power_Break	:1;
	bool Fan_ready		:1;
	bool remote			:1;
	bool Boop			:1;
	uint8_t Battery		:3;
	uint32_t ADC_value;

	uint8_t Fan_duty;
	uint8_t Face_index;
	uint8_t Face_startup_index;
	uint8_t Face_toggle_index;
	uint8_t Matrix_Brightness;
	uint8_t Blink_period;
	uint8_t Beep_period;
	uint8_t Beep_mode;
	uint8_t Neo_Brightness;
	uint32_t ADC_gain;
};

_system_status Blaster;

//EEPROM
#define EEPROM_SIZE						64
#define EEPROM_saved					0xAA
enum _EEPROM
{
	EEPROM_Addr_Saved,
	EEPROM_Addr_Fan_duty,
	EEPROM_Addr_Face_startup_index,
	EEPROM_Addr_Face_toggle_index,
	EEPROM_Addr_Matrix_Brightness,
	EEPROM_Addr_Blink_period,
	EEPROM_Addr_Boop,
	EEPROM_Addr_Beep_period,
	EEPROM_Addr_Beep_mode,
	EEPROM_Addr_Neo_brightness,
	EEPROM_Addr_ADC_gain_HH,
	EEPROM_Addr_ADC_gain_HL,
	EEPROM_Addr_ADC_gain_LH,
	EEPROM_Addr_ADC_gain_LL,
};
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

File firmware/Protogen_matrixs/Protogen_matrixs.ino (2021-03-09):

#include <esp_task_wdt.h>
#include <Wire.h>
#include <BLEDevice.h>
#include <EEPROM.h>
#include <WS2812FX.h>
#include <WS2812Driver.h>
#include <Adafruit_LEDBackpack.h>

#include "./Header Files/option.h"
#include "./Header Files/parameter.h"
#include "./Header Files/GPIO.h"
#include "./Header Files/matrix.h"
#include "./Header Files/Face.h"
#include "./Header Files/neopixel.h"
#include "./Header Files/Bz.h"
#include "./Header Files/music.h"
#include "./Header Files/BLE.h"

void setup()
{
	Serial.begin(115200);
	serial_log(00, "start up");
	gpio_init();

	parameter_init();

	queue_init();

	EEPROM.begin(EEPROM_SIZE);

	/*
	Core_0	Eye, Nose, Mouth, BZ, Fan, Ctrl, BLE
	core_1	Neopixel, Matrix
	*/

	xTaskCreatePinnedToCore(
		Neopixel_task, /* Function to implement the task */
		"Neopixel_task", /* Name of the task */
		Neopixel_task_stack,  /* Stack size in words */
		NULL,  /* Task input parameter */
		Neopixel_task_priority,  /* Priority of the task */
		&Neopixel_task_handle,  /* Task handle. */
		core_1);
	
	xTaskCreatePinnedToCore(
		Matrix_task, /* Function to implement the task */
		"Matrix_task", /* Name of the task */
		Matrix_task_stack,  /* Stack size in words */
		NULL,  /* Task input parameter */
		Matrix_task_priority,  /* Priority of the task */
		&Matrix_task_handle,  /* Task handle. */
		core_1);

	xTaskCreatePinnedToCore(
		Eye_task, /* Function to implement the task */
		"Eye_task", /* Name of the task */
		Eye_task_stack,  /* Stack size in words */
		NULL,  /* Task input parameter */
		Eye_task_priority,  /* Priority of the task */
		&Eye_task_handle,  /* Task handle. */
		core_0);

	xTaskCreatePinnedToCore(
		Nose_task, /* Function to implement the task */
		"Nose_task", /* Name of the task */
		Nose_task_stack,  /* Stack size in words */
		NULL,  /* Task input parameter */
		Nose_task_priority,  /* Priority of the task */
		&Nose_task_handle,  /* Task handle. */
		core_0);

	xTaskCreatePinnedToCore(
		Mouth_task, /* Function to implement the task */
		"Mouth_task", /* Name of the task */
		Mouth_task_stack,  /* Stack size in words */
		NULL,  /* Task input parameter */
		Mouth_task_priority,  /* Priority of the task */
		&Mouth_task_handle,  /* Task handle. */
		core_0);

	xTaskCreatePinnedToCore(
		BZ_task, /* Function to implement the task */
		"BZ_task", /* Name of the task */
		BZ_task_stack,  /* Stack size in words */
		NULL,  /* Task input parameter */
		BZ_task_priority,  /* Priority of the task */
		&BZ_task_handle,  /* Task handle. */
		core_0);

	xTaskCreatePinnedToCore(
		Fan_task, /* Function to implement the task */
		"Fan_task", /* Name of the task */
		Fan_task_stack,  /* Stack size in words */
		NULL,  /* Task input parameter */
		Fan_task_priority,  /* Priority of the task */
		&Fan_task_handle,  /* Task handle. */
		core_0);

	xTaskCreatePinnedToCore(
		Ctrl_task, /* Function to implement the task */
		"Ctrl_task", /* Name of the task */
		Ctrl_task_stack,  /* Stack size in words */
		NULL,  /* Task input parameter */
		Ctrl_task_priority,  /* Priority of the task */
		&Ctrl_task_handle,  /* Task handle. */
		core_0);

	xTaskCreatePinnedToCore(
		BLE_task, /* Function to implement the task */
		"BLE_task", /* Name of the task */
		BLE_task_stack,  /* Stack size in words */
		NULL,  /* Task input parameter */
		BLE_task_priority,  /* Priority of the task */
		&BLE_task_handle,  /* Task handle. */
		core_0);

	serial_log(00, "create task done");
	
	if (EEPROM.read(EEPROM_Addr_Saved) == EEPROM_saved)
	{
		EEPROM_Load();
		serial_log(00, "Load EEPROM done");
	}

	BLE_mode(BLE_mode_boost);
}
    
void loop()
{
	//core 1
	vTaskDelete(NULL); //Kill Loop()
}

void Neopixel_task(void * parameter)
{
	uint8_t mode = 0xFF;
	WS2812FX *neo_ring;
	neo_ring = new WS2812FX(neo_ring_single + 5, LED_PIN, NEO_GRBW + NEO_KHZ800);
	for (;;)
	{
		if (xQueueReceive(queue_Neopixel, &mode, portMAX_DELAY) == pdTRUE)
		{
			switch (mode)
			{
			case Neopixel_mode_boost:
				ws2812driver.init(neo_ring);
				neo_ring->setCustomShow([]() {ws2812driver.customShow(); });
				serial_log(00, "Neopixel_mode_boost");
				vTaskDelay(1 / portTICK_PERIOD_MS);
				Neopixel_mode(Neopixel_mode_set);
				break;

			case Neopixel_mode_general:
				neo_ring->service();
				vTaskDelay(1 / portTICK_PERIOD_MS);
				Neopixel_mode(Neopixel_mode_general);
				break;
				
			case Neopixel_mode_Brightness:
				neo_ring->pause();
				neo_ring->setBrightness(Protogen.Neo_Brightness);
				neo_ring->resume();
				Neopixel_mode(Neopixel_mode_general);
				break;
				
			case Neopixel_mode_set:
				neo_ring->stop();
				neo_ring->setBrightness(Protogen.Neo_Brightness);
				neo_ring->setSpeed((Face_index.neo[1] << 8) + Face_index.neo[2]);
				neo_ring->setColor(Face_index.neo[3], Face_index.neo[4], Face_index.neo[5], Face_index.neo[6]);
				if (Face_index.neo[0] < FX_MODE_MINE)
				{
					neo_ring->setMode(Face_index.neo[0]);
					neo_ring->start();
					Neopixel_mode(Neopixel_mode_general);
				}
				else
				{
					Neopixel_mode(Face_index.neo[0]);
				}
				break;
			}
		}
	}
}
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

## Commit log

2020-12-15 2020/12/15 first commit
    [Blaster_backpack.PrjPcb, Blaster_backpack.xlsx, LED Matrix.xlsx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]
2020-12-16 add PCB Ver2 into repository, and edit a little readme.md
    [20191231_proto_r14_3dsMAX.DXF, 20191231_proto_r14_filled_3dsMAX.DXF, Sheet1.SCHDOC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]
2021-01-06 2020-01-06 add environment setting guide, modify New_gen
    [Mega_app.csv]
2021-01-09 2021-01-09 add bz music driave (untested)
    [LED Matrix.xlsx]
2021-01-09 2021-01-09 fix bug (untested)
    [Protogen_matrixs.ino]
2021-01-09 2021-01-09 BZ music draive done and test complete
    [LED Matrix.xlsx]
2021-01-11 working on music2header
    [LED Matrix.xlsx, LED_Matrix.xlsx, Music_Sheet.xlsx]
2021-01-11 2021-01-11 BZ music sheet fuction complete
    [LED Matrix.xlsx, LED_Matrix.xlsx, Music_Sheet.xlsx]
2021-01-12 2021-01-12 add in doc and edit readme
    [LED_Matrix.xlsx, Music_Sheet.xlsx, Remote_CMD.xlsx]
2021-01-16 add offline reset feature
    [ProtoGun.ino, option.h, parameter.h]
2021-01-22 update Blaster_backpack SCH
    [Sheet1.SchDoc]
2021-01-23 2021/01/23 Re-build Blaster PCB done
    [Blaster_backpack.PrjPcb, PCB1.PcbDoc, Sheet1.SchDoc]
2021-01-23 2021-01-23 add Fan on tomeout
2021-01-23 2021-01-24 Modify ADC fuction, add ADC3
2021-01-24 2021-01-24 modify protogen_matrix GPIO pin mapping
2021-01-25 2021-01-25 archive PCB/ver2
    [20191231_proto_r14_3dsMAX.DXF, 20191231_proto_r14_filled_3dsMAX.DXF, Sheet1.SCHDOC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]
2021-01-25 2021-01-25 modify .gitignore
    [20191231_proto_r14_3dsMAX.DXF, 20191231_proto_r14_filled_3dsMAX.DXF, Sheet1.SCHDOC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]
2021-01-30 2021-01-31 modify .gitignore
    [LED_Matrix.xlsx, Template.xlsx]
2021-01-30 2021-01-31 fix bug in New_gen
    [LED_Matrix.xlsx]
2021-01-30 2021-01-30 edit Template.xlsx
    [Template.xlsx]
2021-01-31 2021-01-31 fix signunature feature bug in ProtoGun
    [ProtoGun.ino]
2021-02-01 2021-02-01 Add in mainboard PCB by wolfgasm
    [Mainboard.SchDoc]
2021-02-02 2021-02-02 update mainboard PCB
    [Mainboard.SchDoc]
2021-02-09 2021-02-09 update MainBoard PCB by Wolfgasm
    [Mainboard.SchDoc]
2021-02-09 2021-02-09 working on Music_Sheet
    [Music_Sheet.xlsx]
2021-02-09 2021-02-09 modify music2header : add close music sheet feature
    [Music_Sheet.xlsx]
2021-02-09 2021-02-09 complete rickroll sheet
    [Music_Sheet.xlsx]
2021-02-19 2021-02-19 optimize Music2header
    [Music_Sheet.xlsx]
2021-03-01 2021-03-01 Modify .gitignore
    [Blaster_backpack.xlsx, PCB_Project.PrjPcb]
2021-03-05 2021-03-05 Add progress bar fuction to Music2header
    [Music_Sheet.xlsx]
2021-03-05 2021-03-05 modify Music2header percentage bar
    [Music_Sheet.xlsx]
2021-03-06 2021-03-06 1. add fsml log for ProtoGun and protomatrix 2. d\fix adc bug for ProtoGun
    [ADC.h, ProtoGun.ino, option.h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]
2021-03-07 2021-03-06 debug ProtoGun and Protogen_matrix
    [Music_Sheet.xlsx, Remote_CMD.xlsx]
2021-03-07 2021-03-07 modify battery break voltage
2021-03-09 2021-03-09 modify bz music and fix bug
    [Music_Sheet.xlsx]
